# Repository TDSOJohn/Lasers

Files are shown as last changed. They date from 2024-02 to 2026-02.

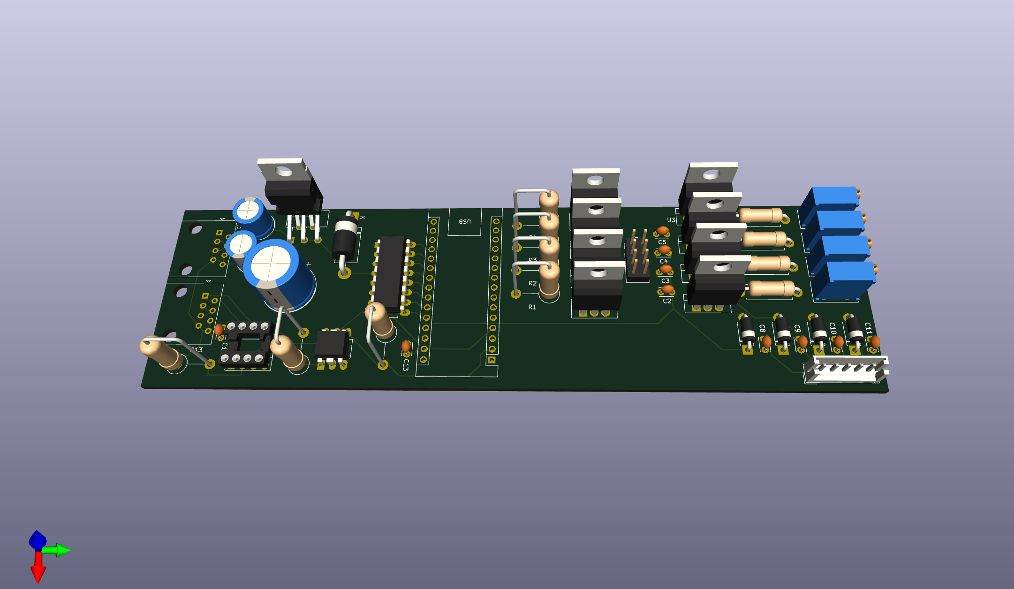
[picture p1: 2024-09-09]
Schematics/export/dmx-to-pwm-board-with-comp.png

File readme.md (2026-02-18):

# Monochrome Laser Bar

This repo contains the schematics and software for the monochrome laser bars used by VirtualConcrete.

Hardware:
- Aluminum body
- Up to 6 laser diodes
- Custom designed pcb with [Arduino Nano](https://docs.arduino.cc/hardware/nano/) and up to 6 laser drivers
- Custom variation of ethernet poe to supply everything with a single RJ45
- DMX over RJ45 control mode
- Fun mode

Software:
- Reads DMX input using [DMXSerial](https://github.com/mathertel/DMXSerial)
- Writes dimmer values as PWM

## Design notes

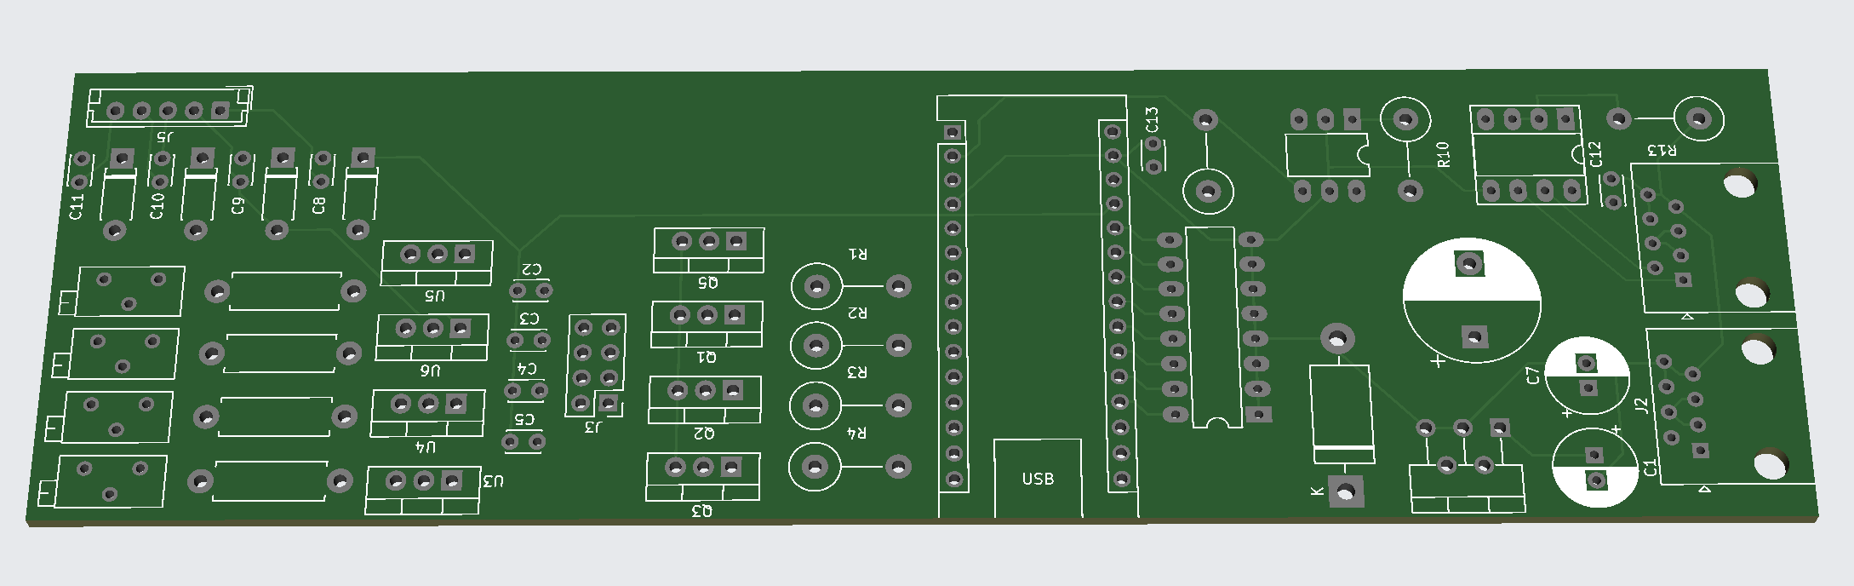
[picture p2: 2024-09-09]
Schematics/export/dmx-to-pwm-board.png

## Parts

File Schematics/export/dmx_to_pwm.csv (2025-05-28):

Reference | Value | Footprint | Datasheet | Qty | DNP
A1 | Arduino_Nano_v3.x | Module:Arduino_Nano | http://www.mouser.com/pdfdocs/Gravitech_Arduino_Nano3_0.pdf | 1
C1 | 47uF - 100V | Capacitor_THT:CP_Radial_D7.5mm_P2.50mm | ~ | 1
C2,C3,C4,C5,C12,C13,C15 | 100nF | Capacitor_THT:C_Disc_D3.0mm_W2.0mm_P2.50mm | ~ | 7
C6 | 33uH | Capacitor_THT:CP_Radial_D8.0mm_P5.00mm | ~ | 1
C7 | 47uF - 16V | Capacitor_THT:CP_Radial_D7.5mm_P2.50mm | ~ | 1
C8,C9,C10,C11,C14,C16 | 1uF | Capacitor_THT:C_Disc_D3.0mm_W2.0mm_P2.50mm | ~ | 6
D1,D3,D4,D5,D6,D7 | 1N4004 | Diode_THT:D_DO-41_SOD81_P7.62mm_Horizontal | http://www.vishay.com/docs/88503/1n4001.pdf | 6
D2 | 1N5822 | Diode_THT:D_DO-201AD_P15.24mm_Horizontal | http://www.vishay.com/docs/88526/1n5820.pdf | 1
J1,J2 | RJ45 | Connector_RJ:RJ45_Amphenol_54602-x08_Horizontal | ~ | 2
J4 | Conn_01x03_Socket | Connector_JST:JST_EH_B3B-EH-A_1x03_P2.50mm_Vertical | ~ | 1
J5 | Conn_02x06_Counter_Clockwise | Connector_PinHeader_2.54mm:PinHeader_2x06_P2.54mm_Vertical | ~ | 1
J6 | Conn_01x07_Socket | Connector_JST:JST_EH_B7B-EH-A_1x07_P2.50mm_Vertical | ~ | 1
Q1,Q2,Q3,Q4,Q5,Q6 | TIP41 | Package_TO_SOT_THT:TO-220-3_Vertical | https://www.centralsemi.com/get_document.php?cmp=1&mergetype=pd&mergepath=pd&pdf_id=tip41.PDF | 6
R1,R2,R3,R4,R5,R11 | 1K | Resistor_THT:R_Axial_DIN0207_L6.3mm_D2.5mm_P7.62mm_Horizontal | ~ | 6
R6,R7,R8,R9,R10,R12 | 2.7 | Resistor_THT:R_Axial_DIN0411_L9.9mm_D3.6mm_P12.70mm_Horizontal | ~ | 6
R13 | 10K | Resistor_THT:R_Axial_DIN0414_L11.9mm_D4.5mm_P7.62mm_Vertical | ~ | 1
RV1,RV2,RV3,RV4,RV5,RV6 | 20 | Potentiometer_THT:Potentiometer_Bourns_3296Z_Horizontal | ~ | 6
SW1 | SW_DIP_x08 | Package_DIP:DIP-16_W7.62mm_LongPads | http://www.ti.com/lit/ds/symlink/cd74hc238.pdf | 1
SW2 | SW_Wuerth | Button_Switch_THT:SW_Slide-03_Wuerth-WS-SLTV_10x2.5x6.4_P2.54mm | https://www.we-online.com/components/products/datasheet/450301014042.pdf | 1
U1,U3,U4,U5,U6,U7 | LM317_TO-220 | Package_TO_SOT_THT:TO-220-3_Vertical | http://www.ti.com/lit/ds/symlink/lm317.pdf | 6
U2 | LM2596T-5 | Package_TO_SOT_THT:TO-220-5_P3.4x3.7mm_StaggerOdd_Lead3.8mm_Vertical | http://www.ti.com/lit/ds/symlink/lm2596.pdf | 1
U8 | SN75176AP | Package_DIP:DIP-8_W7.62mm_Socket_LongPads | http://www.ti.com/lit/ds/symlink/sn75176a.pdf | 1

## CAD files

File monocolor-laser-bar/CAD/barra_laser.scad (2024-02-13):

$fn = 16;

module blocchetto_laser() {
    difference() {
        cube([2.5, 2.5, 1]);    
        
        translate([0.35, 0.35, 0])
            cylinder(3, 0.15, 0.15, center = true);
        translate([0.35, 2.15, 0])
            cylinder(3, 0.15, 0.15, center = true);
        translate([2.15, 0.35, 0])
            cylinder(3, 0.15, 0.15, center = true);
        translate([2.15, 2.15, 0])
            cylinder(3, 0.15, 0.15, center = true);
        translate([1.25, 1.25, 0.2])
            cylinder(3, 0.75, 0.75);
        translate([1.25, 1.25, -0.1])
            cylinder(3, 0.5, 0.5);
    }
}

module laser_module() {
    translate([0, 0, -0.1])
        cylinder(h=3.2, r=0.5);
}

module locking_module() {
    translate([0, 0, -0.1])
        cylinder(h=2.2, r=0.4);
}

module bucket_module() {
    translate([0, 0, 0.75])
    color([0.5, 0.5, 0.5])
        cylinder(h=1, r=0.15);
    translate([0.8, 3, 0.75])
    color([0.5, 0.5, 0.5])
        cylinder(h=1, r=0.15);
}

module dmx_driver_module() {
    translate([1.375, 5.25, 0.75])
    color([0.5, 0.5, 0.5])
        cylinder(h=1, r=0.15);
    translate([-1.375, 5.25, 0.75])
    color([0.5, 0.5, 0.5])
        cylinder(h=1, r=0.15);
    translate([-0.7, -5.25, 0.75])
    color([0.5, 0.5, 0.5])
        cylinder(h=1, r=0.15);
}

module bucket_converter() {
    color([0, 0, 1])
        cube([2.1, 4.35, 1.5]);
}

module dmx_driver() {
    color([0.2, 0.2, 0.2])
        cube([4.1, 15.2, 2.3]);
    translate([2.2, 13.6, 0])
    color([0.8, 0.8, 0])
        cube([1.8, 4.8, 1.5]);
    translate([0.1, 13.6, 0])
    color([0.8, 0.8, 0])
        cube([1.8, 4.8, 1.5]);
}

module antenna_circuit() {
    translate([0, 0, 0.8])
    color([0, 0.6, 0.6])
        cube([1.55, 6.7, 1]);
}

module laser_driver() {
    color([0, 0.7, 0.3])
        cube([0.85, 2, 0.5]);
}

$fa = 2;
$fs = 0.2;

translate([0.3, 55, 1.5]) bucket_converter();
translate([2.6, 55, 1.5]) bucket_converter();
translate([0.3, 68, 1.5]) bucket_converter();
translate([2.6, 68, 1.5]) bucket_converter();

translate([0.45, 74, 0.75]) dmx_driver();

translate([1.725, 20, 0.75]) antenna_circuit();

translate([2.075, 39, 1.5]) laser_driver();
translate([2.075, 60.5, 1.5]) laser_driver();
translate([0.475, 97, 1.5]) laser_driver();
translate([2.075, 9, 1.5]) laser_driver();

translate([1.25, 3.75, 1.5]) blocchetto_laser();
translate([1.25, 33.75, 1.5]) blocchetto_laser();
translate([1.25, 63.75, 1.5]) blocchetto_laser();
translate([1.25, 93.75, 1.5]) blocchetto_laser();

difference() {
    cube([5, 100, 1.5]);

    locking_module();
    translate([2.5, 2, 0]) locking_module();
    translate([2.5, 50, 0]) locking_module();
    translate([2.5, 98, 0]) locking_module();
    
    translate([2.5, 5, 0]) laser_module();
    translate([2.5, 35, 0]) laser_module();
    translate([2.5, 65, 0]) laser_module();
    translate([2.5, 95, 0]) laser_module();
    
    translate([0.8, 55.525, 0]) bucket_module();
    translate([3.1, 55.525, 0]) bucket_module();
    translate([0.8, 68.525, 0]) bucket_module();
    translate([3.1, 68.525, 0]) bucket_module();
}

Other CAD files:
3D Models/laser_module.blend

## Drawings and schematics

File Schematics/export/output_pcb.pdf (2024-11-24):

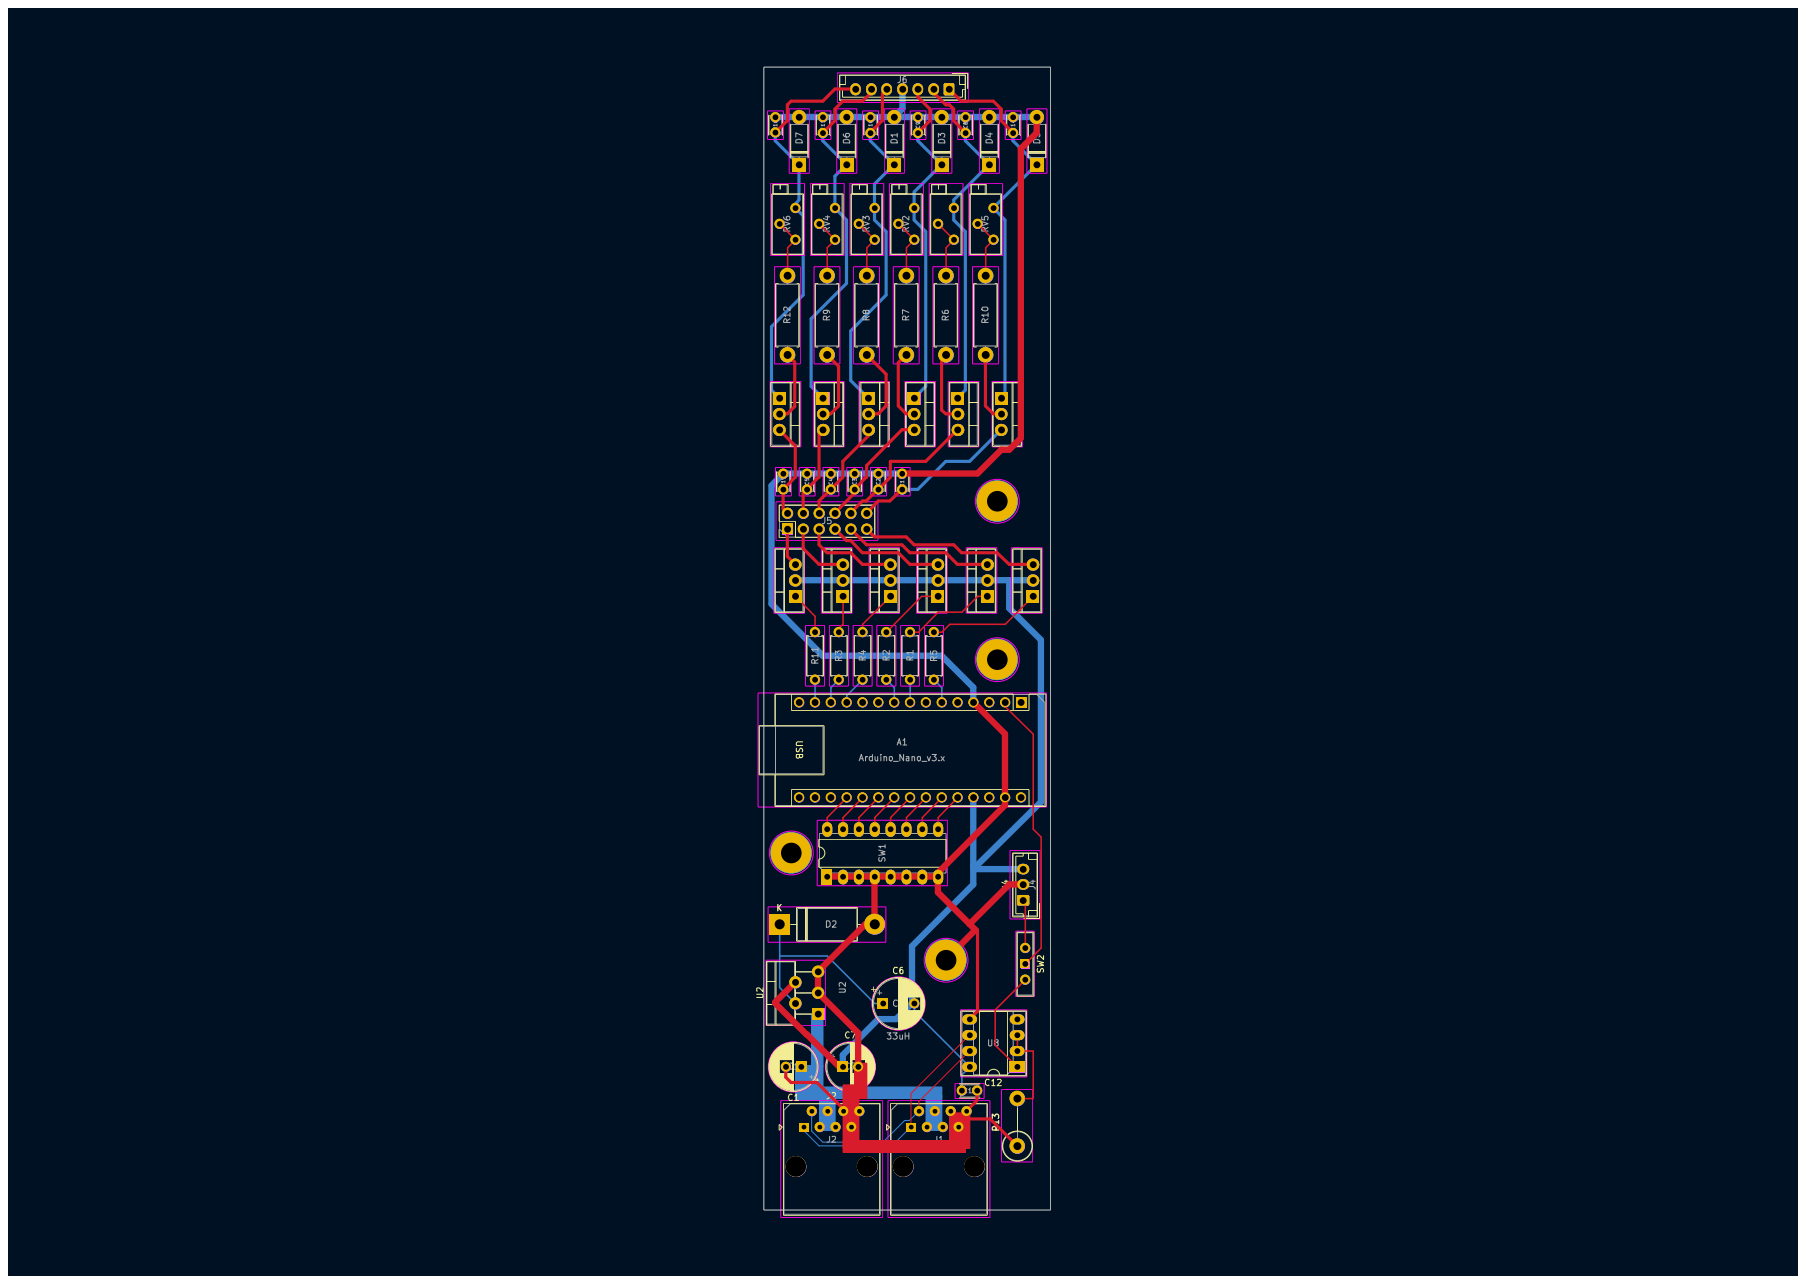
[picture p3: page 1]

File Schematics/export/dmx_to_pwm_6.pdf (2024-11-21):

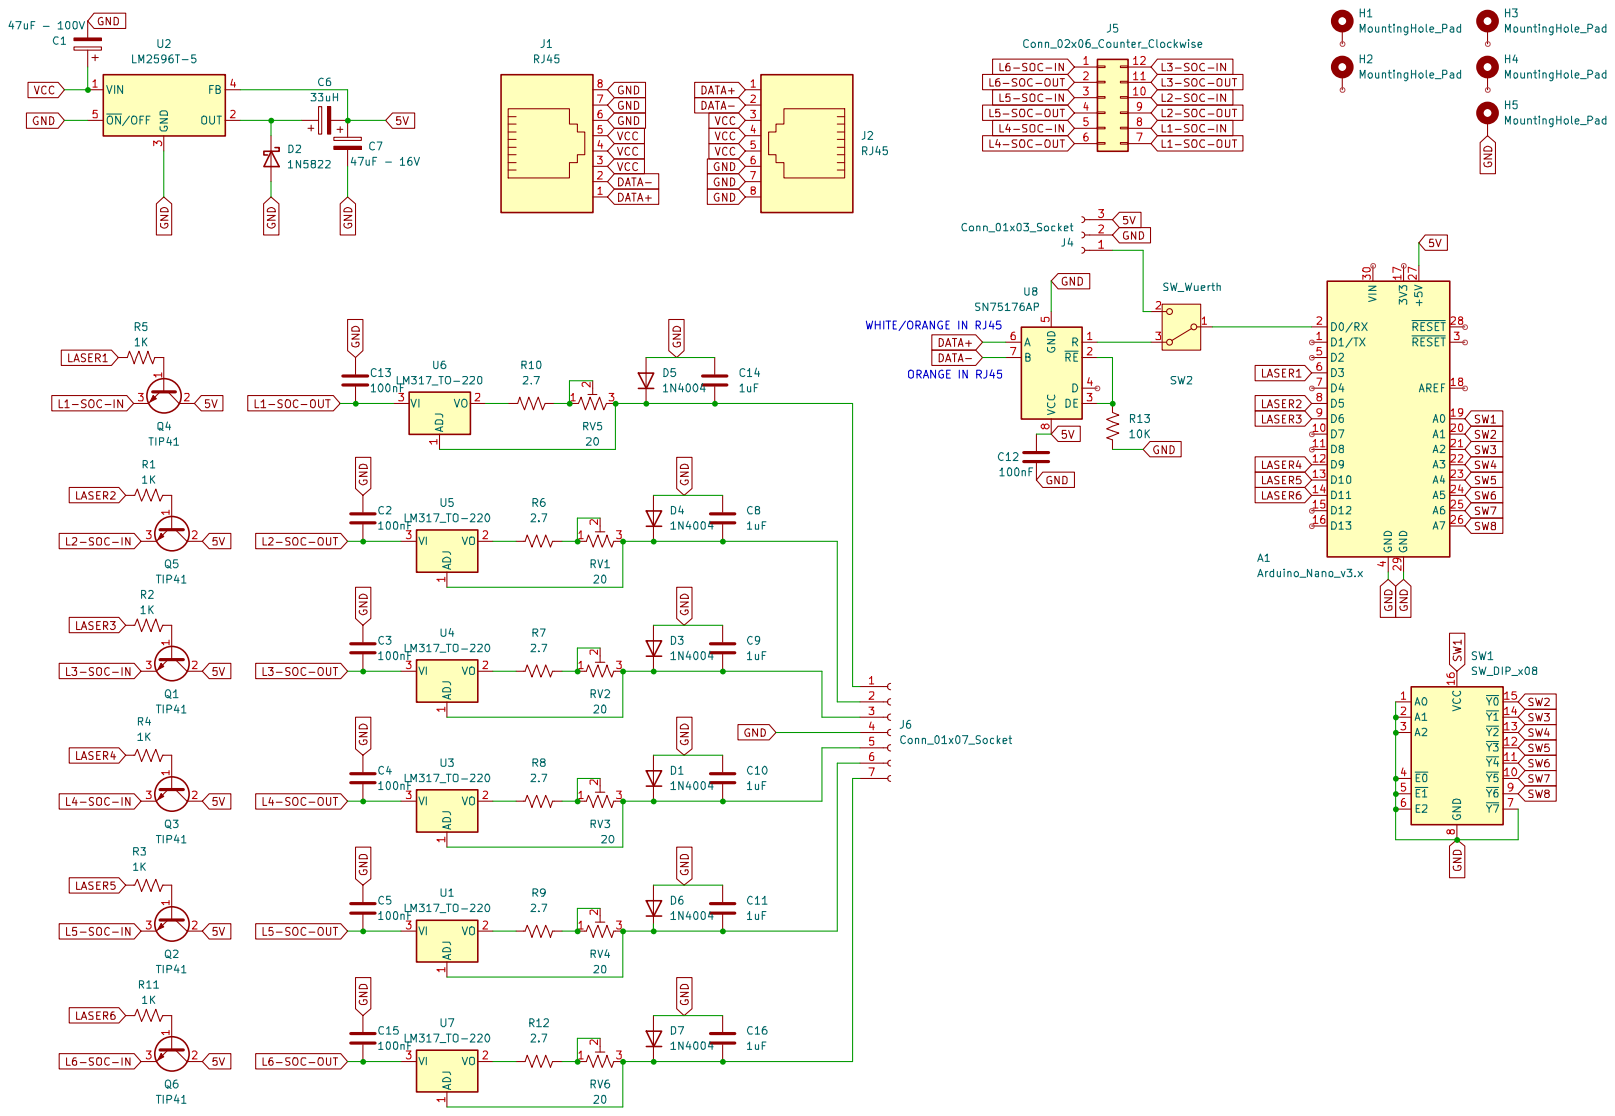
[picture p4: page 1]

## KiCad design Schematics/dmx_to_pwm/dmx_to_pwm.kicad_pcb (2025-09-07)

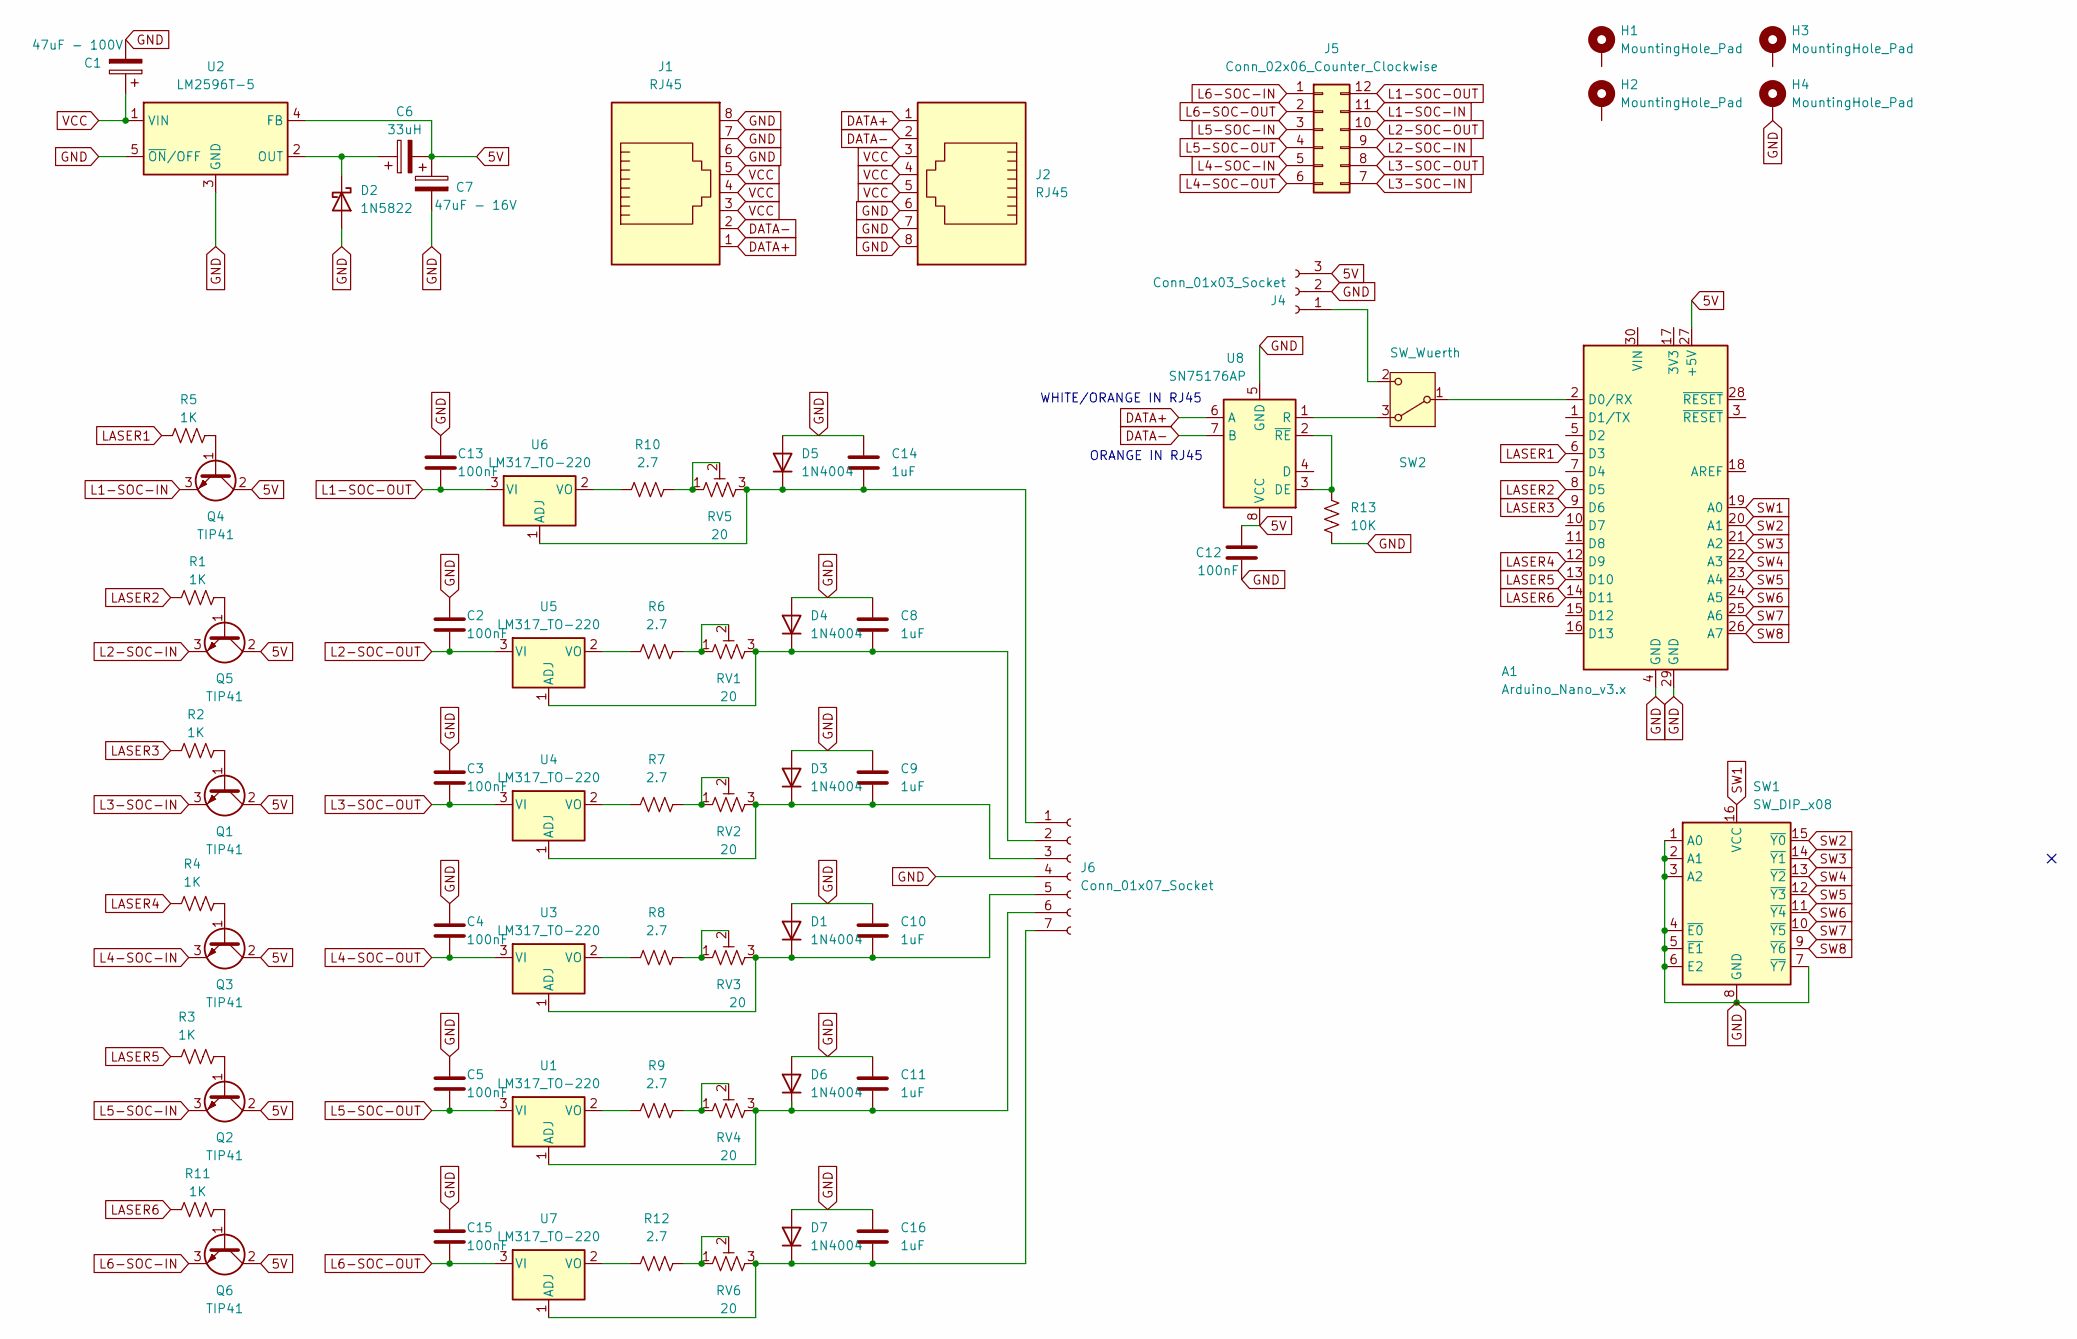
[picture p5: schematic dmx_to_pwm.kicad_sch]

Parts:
A1: Arduino_Nano_v3.x; Arduino_Nano
C1: 47uF - 100V; CP_Radial_D7.5mm_P2.50mm
C2, C3, C4, C5, C12, C13, C15: 100nF; C_Disc_D3.0mm_W2.0mm_P2.50mm
C6: 33uH; CP_Radial_D8.0mm_P5.00mm
C7: 47uF - 16V; CP_Radial_D7.5mm_P2.50mm
C8, C9, C10, C11, C14, C16: 1uF; C_Disc_D3.0mm_W2.0mm_P2.50mm
D1, D3, D4, D5, D6, D7: 1N4004; D_DO-41_SOD81_P7.62mm_Horizontal
D2: 1N5822; D_DO-201AD_P15.24mm_Horizontal
H1, H2, H3, H4: MountingHole_Pad; MountingHole_3.2mm_M3_Pad
J1, J2: RJ45; RJ45_Amphenol_54602-x08_Horizontal
J4: Conn_01x03_Socket; JST_EH_B3B-EH-A_1x03_P2.50mm_Vertical
J5: Conn_02x06_Counter_Clockwise; PinHeader_2x06_P2.54mm_Vertical
J6: Conn_01x07_Socket; JST_EH_B7B-EH-A_1x07_P2.50mm_Vertical
Q1, Q2, Q3, Q4, Q5, Q6: TIP41; TO-220-3_Vertical
R1, R2, R3, R4, R5, R11: 1K; R_Axial_DIN0207_L6.3mm_D2.5mm_P7.62mm_Horizontal
R6, R7, R8, R9, R10, R12: 2.7; R_Axial_DIN0411_L9.9mm_D3.6mm_P12.70mm_Horizontal
R13: 10K; R_Axial_DIN0414_L11.9mm_D4.5mm_P7.62mm_Vertical
RV1, RV2, RV3, RV4, RV5, RV6: 20; Potentiometer_Bourns_3296Z_Horizontal
SW1: SW_DIP_x08; DIP-16_W7.62mm_LongPads
SW2: SW_Wuerth; SW_Slide-03_Wuerth-WS-SLTV_10x2.5x6.4_P2.54mm
U1, U3, U4, U5, U6, U7: LM317_TO-220; TO-220-3_Vertical
U2: LM2596T-5; TO-220-5_P3.4x3.7mm_StaggerOdd_Lead3.8mm_Vertical
U8: SN75176AP; DIP-8_W7.62mm_Socket_LongPads

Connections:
5V: A1.27 (+5V), C6.2, C7.1, C12.1, J4.3, Q1.2 (C), Q2.2 (C), Q3.2 (C), Q4.2 (C), Q5.2 (C), Q6.2 (C), U2.4 (FB), U8.8 (VCC)
DATA+: J1.1, J2.1, U8.6 (A)
DATA-: J1.2, J2.2, U8.7 (B)
GND: A1.4 (GND), A1.29 (GND), C1.2, C2.1, C3.1, C4.1, C5.1, C7.2, C8.1, C9.1, C10.1, C11.1, C12.2, C13.1, C14.1, C15.1, C16.1, D1.2 (A), D2.2 (A), D3.2 (A), D4.2 (A), D5.2 (A), D6.2 (A), D7.2 (A), H4.1, J1.6, J1.7, J1.8, J2.6, J2.7, J2.8, J4.2, J6.4, R13.1, SW1.1 (A0), SW1.2 (A1), SW1.3 (A2), SW1.4 (~E0), SW1.5 (~E1), SW1.6 (E2), SW1.7 (~Y7), SW1.8 (GND), U2.3 (GND), U2.5 (~ON/OFF), U8.5 (GND)
L1-SOC-IN: J5.11, Q4.3 (E)
L1-SOC-OUT: C13.2, J5.12, U6.3 (VI)
L2-SOC-IN: J5.9, Q5.3 (E)
L2-SOC-OUT: C2.2, J5.10, U5.3 (VI)
L3-SOC-IN: J5.7, Q1.3 (E)
L3-SOC-OUT: C3.2, J5.8, U4.3 (VI)
L4-SOC-IN: J5.5, Q3.3 (E)
L4-SOC-OUT: C4.2, J5.6, U3.3 (VI)
L5-SOC-IN: J5.3, Q2.3 (E)
L5-SOC-OUT: C5.2, J5.4, U1.3 (VI)
L6-SOC-IN: J5.1, Q6.3 (E)
L6-SOC-OUT: C15.2, J5.2, U7.3 (VI)
LASER1: A1.6 (D3), R5.2
LASER2: A1.8 (D5), R1.2
LASER3: A1.9 (D6), R2.2
LASER4: A1.12 (D9), R4.2
LASER5: A1.13 (D10), R3.2
LASER6: A1.14 (D11), R11.2
unnamed: A1.2 (D0/RX), SW2.1 (B)
unnamed: C10.2, D1.1 (K), J6.5, RV3.3, U3.1 (ADJ)
unnamed: C6.1, D2.1 (K), U2.2 (OUT)
unnamed: C9.2, D3.1 (K), J6.3, RV2.3, U4.1 (ADJ)
unnamed: C8.2, D4.1 (K), J6.2, RV1.3, U5.1 (ADJ)
unnamed: C14.2, D5.1 (K), J6.1, RV5.3, U6.1 (ADJ)
unnamed: C11.2, D6.1 (K), J6.6, RV4.3, U1.1 (ADJ)
unnamed: C16.2, D7.1 (K), J6.7, RV6.3, U7.1 (ADJ)
unnamed: J4.1, SW2.2 (C)
unnamed: Q1.1 (B), R2.1
unnamed: Q2.1 (B), R3.1
unnamed: Q3.1 (B), R4.1
unnamed: Q4.1 (B), R5.1
unnamed: Q5.1 (B), R1.1
unnamed: Q6.1 (B), R11.1
unnamed: R6.1, RV1.1, RV1.2
unnamed: R7.1, RV2.1, RV2.2
unnamed: R8.1, RV3.1, RV3.2
unnamed: R9.1, RV4.1, RV4.2
unnamed: R10.1, RV5.1, RV5.2
unnamed: R12.1, RV6.1, RV6.2
unnamed: SW2.3 (A), U8.1 (R)
unnamed: R9.2, U1.2 (VO)
unnamed: R8.2, U3.2 (VO)
unnamed: R7.2, U4.2 (VO)
unnamed: R6.2, U5.2 (VO)
unnamed: R10.2, U6.2 (VO)
unnamed: R12.2, U7.2 (VO)
unnamed: R13.2, U8.2 (~RE), U8.3 (DE)
SW1: A1.19 (A0), SW1.16 (VCC)
SW2: A1.20 (A1), SW1.15 (~Y0)
SW3: A1.21 (A2), SW1.14 (~Y1)
SW4: A1.22 (A3), SW1.13 (~Y2)
SW5: A1.23 (A4), SW1.12 (~Y3)
SW6: A1.24 (A5), SW1.11 (~Y4)
SW7: A1.25 (A6), SW1.10 (~Y5)
SW8: A1.26 (A7), SW1.9 (~Y6)
VCC: C1.1, J1.3, J1.4, J1.5, J2.3, J2.4, J2.5, U2.1 (VIN)

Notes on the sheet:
WHITE/ORANGE IN RJ45
ORANGE IN RJ45

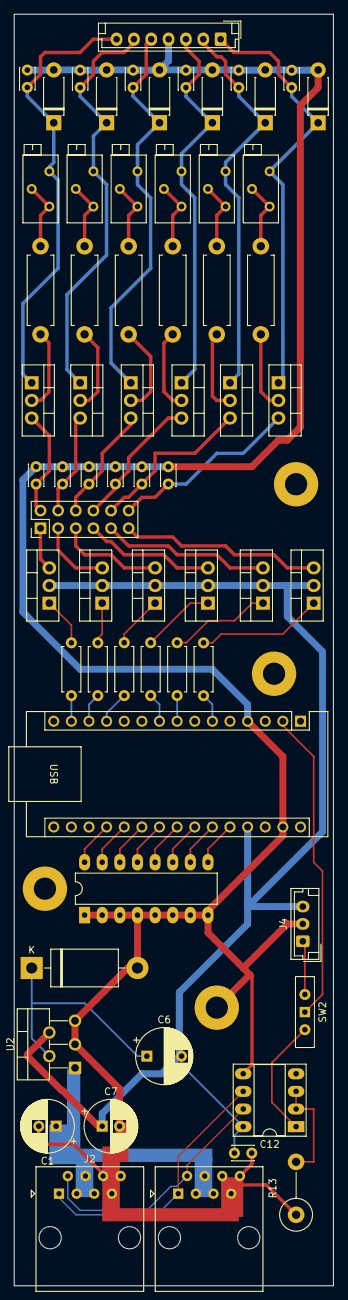
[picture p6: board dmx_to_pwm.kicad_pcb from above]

Board: 2 copper layers, 46.0 x 183.2 mm, 68 parts (0 on the bottom side), 60 nets.

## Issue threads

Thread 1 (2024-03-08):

Aggiornamento preventivo

TDSOJohn, 2024-03-08:
Aggiungere prezzi:

- scatola di derivazione
- attacchi IP68
- macchina del fumo e stima spesa del liquido
- mastice isolante per cavi
- guaina termorestringente
- mascherina ethernet
- cablaggio barra
- stima costi cavi ethernet con misure reali
- struttura di supporto per la macchina del fumo
- alimentazione delle barre

Megazord0, 2024-03-13:
Mida alluminio

- 6,50 m
14,396 euro al k per 5 kg

71.98 euri

- 19,5 m
13.176 euro al kg per 15kg

197.64 euri

- 32,5 m 13.176 euro al kg per 25 kg

329.4 euro
*prezzi già ivati
Da aggiungere extra di 35 euri per la fatturazione

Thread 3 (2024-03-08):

Progettazione architettonica

TDSOJohn, 2024-03-08:
- Calcolare lunghezze cavi
- Posizioni macchine del fumo
- Posizioni alimentatori / distribuzione dell'energia
- Posizione scatola di derivazione per ogni barra

Megazord0, 2024-03-15:
La macchina del fumo da 1500w FX

- Riscaldamento
si scalda a pieno regime più o meno in 3 minuti, inizia a sparare da 2 e 15”

- Tenuta in temperatura
non rilevati particolari tempi di recupero, si ferma pochi secondi prima di gittare di nuovo se al 100% della potenza e ancora meno se al 40%

- Consumi

Al 40% consuma 20cl in 7:30 minuti

la sua tanica interna (2,5 litri) in 130 minuti

la tanica da 10 litri in 8 ore e mezza

Al 100% consuma 20cl in 6:10 minuti

la sua tanica interna (2,5 litri) in 116 minuti

la tanica da 10 litri in 7 ore e 45 minuti

Ipotesi di utilizzo per serata?

Costi liquido fx 14,50 euro per 5 litri

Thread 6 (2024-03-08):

Sicurezza

TDSOJohn, 2024-03-08:
- Trovare ingegnere della sicurezza
- Inviare sheet e dati all'ingegnere della struttura
- Parlare con l'ingegnere del DumBO

Megazord0, 2024-03-13:
Brief Alan (Strutturalista)

dubbi sul materiale

questione torsione non è un problema

ok per scarico pesi della barra
problema tasselli sul soffitto per macchina del fumo

problema tasselli nei tondini

Soluzioni proposte

Cercare profili in acciaio

chiedere un prev al fabbro

Da fare
dare a Alan quantità di fori per farsi fare preventivo installazione

Megazord0, 2024-04-03:
Brief Alan 03/04/24 (Strutturalista)

Serve un ingegnere elettronico per certificare il progetto dell’impianto elettrico e un elettricista per certificare l’installazione.

il ferro/alluminio è certificato dal produttore

non serve una certificazione per i fori

se serve una firma sul progetto dei profili può pensarci Alan

Fabbri che fanno anche installazione

trovare un elettricista

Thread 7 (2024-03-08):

Simulazione

TDSOJohn, 2024-03-08:
- Collegare Blender a QLC+
- Fare modello 3d delle barre con la seconda disposizione
- Migliorare realismo angolo di visione del laser
- Aggiungere simulazione nebbia / fumo

Megazord0, 2024-04-03:
**Pattern Test**

- Plain Color : play con fade in e out a 500ms
- Alternate : con colori sulla stessa sfumatura ( rosso/arancione)
- Balls :  monocolor/ bicolor (bianco/rosso) 50ms / fade in - fade out / anche abbassando velocità e aumentando fade i/o
- Blinder:  sia lento che veloce con fade i/o
- Circles : interessante
- Even/odd : Hold 140 ms F/out 500 F/in 500
- Fill: 126 ms tutti gloi orientamenti fanno animazionioni diverse
- Fill From centre: Variazione cromatica arcobalenosa - F/on 402ms Hold 84ms
- Fill Unfill : 84 bms - Vertical
- Fill unfill From centre: Variazione cromatica arcobalenosa - F/on 402ms Hold 84ms
- Fill unfill squares from centre: 127ms
- Fireworks: 5 5 8 127ms
- Flying objects: 127ms 50 ms. f/i f/o
- Gradient: 50 ms e anche  f/i f/o
- Lines :  tutte le Type da usare una dopo l'altro per fare video anche con f/in
- Noise: Hold 108ms Coverage Low
- One by one: Hold 50ms F/o 315

Altri da aggiungere

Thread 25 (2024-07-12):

Comprare materiale mancante

TDSOJohn, 2024-07-12:
- [x] Carrello amazon
- [ ] Carrello RS
- [ ] Diodi laser vecchi x30 + nuovi Nx1 da testare

TDSOJohn, 2024-08-22:
- [] Comprare filo

Closed 2024-08-27.

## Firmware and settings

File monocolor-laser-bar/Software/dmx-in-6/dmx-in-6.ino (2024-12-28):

#include <DMXSerial.h>

#include "data.h"

int bar_id = 0;

const int Laser1 = 3;
const int Laser2 = 5;
const int Laser3 = 6;
const int Laser4 = 9;
const int Laser5 = 10;
const int Laser6 = 11;

int startChannel = 0;

#define DefaultLevel 255

byte speed = 20;

// 0 for ALL ON
// 1 for DMX MODE
byte mode = 1;

void setup() {
  // initialize dmx serial as receiver
  DMXSerial.init(DMXReceiver);
  
  DMXSerial.write(1, DefaultLevel);
  DMXSerial.write(2, DefaultLevel);
  DMXSerial.write(3, DefaultLevel);
  DMXSerial.write(4, DefaultLevel);
  DMXSerial.write(5, DefaultLevel);
  DMXSerial.write(6, DefaultLevel);

  pinMode(Laser1, OUTPUT);
  pinMode(Laser2, OUTPUT);
  pinMode(Laser3, OUTPUT);
  pinMode(Laser4, OUTPUT);
  pinMode(Laser5, OUTPUT);
  pinMode(Laser6, OUTPUT);

  analogWrite(Laser1, DefaultLevel);
  analogWrite(Laser2, DefaultLevel);
  analogWrite(Laser3, DefaultLevel);
  analogWrite(Laser4, DefaultLevel);
  analogWrite(Laser5, DefaultLevel);
  analogWrite(Laser6, DefaultLevel);

  
  pinMode(A0, INPUT_PULLUP);
  pinMode(A1, INPUT_PULLUP);
  pinMode(A2, INPUT_PULLUP);
  pinMode(A3, INPUT_PULLUP);
  pinMode(A4, INPUT_PULLUP);
  pinMode(A5, INPUT_PULLUP);
  pinMode(A6, INPUT_PULLUP);
  pinMode(A7, INPUT_PULLUP);
  delay(50);
  bar_id = !digitalRead(A0);
  delay(50);
  bar_id += (!digitalRead(A1) * 2);
  delay(50);
  bar_id += (!digitalRead(A2) * 4);
  delay(50);
  bar_id += (!digitalRead(A3) * 8);

  startChannel = bar_id * 6 + 1;
}

int step = 0;

void loop() {
  unsigned long lastPacket = DMXSerial.noDataSince();

  if(mode == 1 && lastPacket < 10000) {
    analogWrite(Laser1, DMXSerial.read(startChannel));
    analogWrite(Laser2, DMXSerial.read(startChannel + 1));
    analogWrite(Laser3, DMXSerial.read(startChannel + 2));
    analogWrite(Laser4, DMXSerial.read(startChannel + 3));
    analogWrite(Laser5, DMXSerial.read(startChannel + 4));
    analogWrite(Laser6, DMXSerial.read(startChannel + 5));
  } else {
      analogWrite(Laser1, DefaultLevel);
      analogWrite(Laser2, DefaultLevel);
      analogWrite(Laser3, DefaultLevel);
      analogWrite(Laser4, DefaultLevel);
      analogWrite(Laser5, DefaultLevel);
      analogWrite(Laser6, DefaultLevel);
      delay(100);
  }
}

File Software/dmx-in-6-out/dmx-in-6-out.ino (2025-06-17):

#include <DMXSerial.h>
#include "data.h"


int num_of_lasers = 4;

// set using DIP switches on the pcb
int start_channel = 1;

const int laserOut[6] = {3, 5, 6, 9, 10, 11};
int funModeVal[6] = {0, 0, 0, 0, 0, 0};

const int primes[6] = {1, 2, 3, 5, 7, 11};

const int defaultLevel = 0;

byte speed = 20;

// 0 = DMX
// 1 = FUN
// 2 = ALL ON
// DIP switch all 1 (value 255): fun mode
byte mode = 0;


void setup() {
  // initialize dmx serial as receiver
  DMXSerial.init(DMXReceiver);

  for(int i = 0; i < num_of_lasers; i++) {
    pinMode(laserOut[i], OUTPUT);
    delay(200);
    analogWrite(laserOut[i], 255);
  }

  for(int i = A0; i <= A5; i++)
    pinMode(i, INPUT_PULLUP);
  delay(50);
  
  start_channel = !digitalRead(A0);
  delay(50);
  start_channel += (!digitalRead(A1) * 2);
  delay(50);
  start_channel += (!digitalRead(A2) * 4);
  delay(50);
  start_channel += (!digitalRead(A3) * 8);
  delay(50);
  start_channel += (!digitalRead(A4) * 16);
  delay(50);
  start_channel += (!digitalRead(A5) * 32);
  delay(50);

  if(start_channel == 0)
    mode = 2;
  else if(start_channel == 63)
    mode = 1;

  for(int i = 0; i < num_of_lasers; i++)
    DMXSerial.write(start_channel + i, defaultLevel);
}


void loop() {
  unsigned long lastPacket = DMXSerial.noDataSince();

  // DMX mode and last packet < 10s
  if(mode == 0 && lastPacket < 10000) {
    for(int i = 0; i < num_of_lasers; i++)
      analogWrite(laserOut[i], DMXSerial.read(start_channel + i));
  } else if(mode == 0 && lastPacket >= 10000) {
  // DMX mode and last packet > 10s
    for(int i = 0; i < num_of_lasers; i++)
      analogWrite(laserOut[i], defaultLevel);
    delay(100);
  } else if(mode == 1) {
  // FUN mode
    for(int i = 0; i < num_of_lasers; i++)
      analogWrite(laserOut[i], rand() % 256);
    delay(250);
  } else {
  // ALL ON mode
    for(int i = 0; i < num_of_lasers; i++)
      analogWrite(laserOut[i], 255);
    delay(25);
  }
}

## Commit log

2023-01-10 Added mainboard schematics
2024-02-03 added alluminum bar cad
    [barra_laser.scad]
2024-02-04 added antenna footprint
    [barra_laser.scad]
2024-02-05 added laser drivers
    [barra_laser.scad]
2024-02-13 added laser blocks, improved laser bar
    [barra_laser.scad, blocco_laser.scad]
2024-02-17 added project for 2 colliders
    [2_allineatori.scad]
2024-02-22 dmx to pwm first commit
    [dmx_to_pwm.kicad_pcb, dmx_to_pwm.kicad_sch]
2024-02-26 updated dmx-to-pwm schematics
    [dmx_to_pwm.kicad_sch]
2024-02-29 added software to dimmer rgb
    [barra_rgb.scad]
2024-02-29 added some exports
    [barra_rgb.3mf, barra_rgb.amf, barra_rgb.stl]
2024-02-29 updated bar size
    [barra_rgb.scad, barra_rgb.stl]
2024-02-29 added blocco laser export
    [blocco_laser.scad, blocco_laser.stl]
2024-02-29 added blocco laser stp export
    [blocco_laser_stp.stp]
2024-02-29 updated to kicad version 8.0
    [dmx_to_pwm.kicad_sch]
2024-03-01 updated some components
    [dmx_to_pwm.kicad_pcb, dmx_to_pwm.kicad_sch]
2024-03-05 improved schematics
    [dmx_to_pwm.kicad_sch]
2024-03-08 #7 added rgb diode volume
    [barra_rgb.3mf, barra_rgb.amf, barra_rgb.scad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]
2024-03-08 #5 improved schematics
    [dmx_to_pwm.kicad_pcb, dmx_to_pwm.kicad_sch]
2024-03-11 added some prototype info to the schematics
    [dmx_to_pwm.kicad_sch]
2024-03-23 updated schematics, added laser module blender file
    [barra_rgb.scad, barra_rgb_60x30x3.stl, dmx_to_pwm.kicad_pcb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]
2024-03-29 render is now properly working with qlc+
    [laser_module.blend]
2024-06-19 cleaned up files and folders
    [2_allineatori.scad, barra_laser.scad, barra_rgb.3mf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]
2024-06-19 improved folder structure, deleted useless file
    [dmx_to_pwm.kicad_pcb, dmx_to_pwm.kicad_sch]
2024-06-26 added pdf schematics
    [dmx_to_pwm.kicad_sch]
2024-07-07 added smoke machine schematics
    [macchina_del_-fumo.kicad_pcb, macchina_del_-fumo.kicad_sch]
2024-07-14 added interrupt code
2024-08-21 Added drivers to monochrome schematics
    [dmx_to_pwm.kicad_sch]
2024-09-04 updated schematics
    [dmx_to_pwm.kicad_sch]
2024-09-04 updated rj45
    [dmx_to_pwm.kicad_sch]
2024-09-04 first pcb layout
    [dmx_to_pwm.kicad_pcb, dmx_to_pwm.kicad_sch]
2024-09-09 added board
    [dmx_to_pwm.kicad_pcb, dmx_to_pwm.kicad_sch]
2024-09-09 added gerber output
    [dmx_to_pwm_B_Cu.gbl, dmx_to_pwm_B_Mask.gbs, dmx_to_pwm_B_Paste.gbp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]
2024-09-09 uploaded artifacts
    [dmx_to_pwm-B_Cu.gbl, dmx_to_pwm-B_Mask.gbs, dmx_to_pwm-B_Paste.gbp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]
2024-09-09 updated artifacts
    [dmx_to_pwm-B_Cu.gbl, dmx_to_pwm-B_Mask.gbs, dmx_to_pwm-B_Paste.gbp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]
2024-09-09 updated max patches
    [dmx_to_pwm.kicad_pcb]
2024-09-13 added 6 laser control code
2024-09-15 updated arduino code
2024-10-20 improved pcb track width, added antenna connector
    [dmx_to_pwm.kicad_pcb, dmx_to_pwm.kicad_sch]
2024-10-20 added dip switch code
2024-11-21 updated schematics to 6 lasers
    [dmx_220_driver.kicad_pcb, dmx_220_driver.kicad_sch, dmx_to_pwm.kicad_pcb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]
2024-11-21 updated pcb for 6 lasers
    [dmx_to_pwm.kicad_pcb, dmx_to_pwm.kicad_sch]
2024-11-24 improved pcb
    [dmx_to_pwm.kicad_pcb]
2024-12-03 improved arduino code
2024-12-28 cleaned repo
    [2_allineatori.scad, barra_laser.scad, barra_rgb.3mf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]
2025-01-07 updated CADs
    [2_allineatori.scad, barra-laser.scad, blocco-laser.scad]
2025-01-21 fixed some arduino code
2025-05-28 updated schematics and software
    [dmx_to_pwm.csv, dmx_to_pwm.kicad_sch, dmx_to_pwm_bom.csv]
2025-06-17 deleted useless rgb stuff
    [barra_rgb.3mf, barra_rgb.amf, barra_rgb.scad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]
2025-09-07 updated to v9
    [dmx_to_pwm.kicad_pcb]
2025-10-21 analog write on wrong pin gave funny output
2026-02-12 Only laser stuff remaining
    [barra-laser.scad, blocco-laser.scad, blocco_laser.stl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]
2026-02-18 deleted some useless stuff
    [barra-laser.scad, blocco-laser.scad, blocco_laser.stl]
